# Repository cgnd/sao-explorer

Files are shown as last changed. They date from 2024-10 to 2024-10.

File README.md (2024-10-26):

---
typora-copy-images-to: ./images
---

# SAO Explorer v1

The SAO Explorer v1 is a [Simple Add-on](https://hackaday.io/project/175182-simple-add-ons-sao) (SAO) board that breaks out the 2x3 0.100" (2.54mm) SAO v2 header into a [mikroBUS](https://www.mikroe.com/mikrobus) socket and a couple SparkFun [Qwiic](https://www.sparkfun.com/qwiic) connectors. This makes it really easy to connect hundreds of different I2C breakout boards to a SAO host board—like a [Supercon badge](https://hackaday.com/2023/10/18/2023-hackaday-supercon-badge-welcome-to-the-vectorscope/)!—by quickly plugging in [MikroE Click](https://www.mikroe.com/click?interface*=i2c,i2c), [SparkFun Qwiic](https://www.sparkfun.com/categories/399), or [Adafruit STEMMA QT](https://www.adafruit.com/category/620) boards. No soldering required!

It also has a 2x5 0.050" (1.27mm) socket that allows a [Binho Nova](https://binho.io/products/usb-host-adaptor?variant=14141584343095) Multi-Protocol USB Host Adapter to be used as an I2C controller (instead of a badge). The [Binho Mission Control Software](https://support.binho.io/getting-started/binho-mission-control/download-and-installation) provides an easy-to-use GUI interface for quickly testing out new I2C devices without having to write a single line of code.

Entry for the [Supercon 8 - Add On Contest](https://hackaday.io/contest/197237-supercon-8-add-on-contest): https://hackaday.io/project/198465-sao-explorer

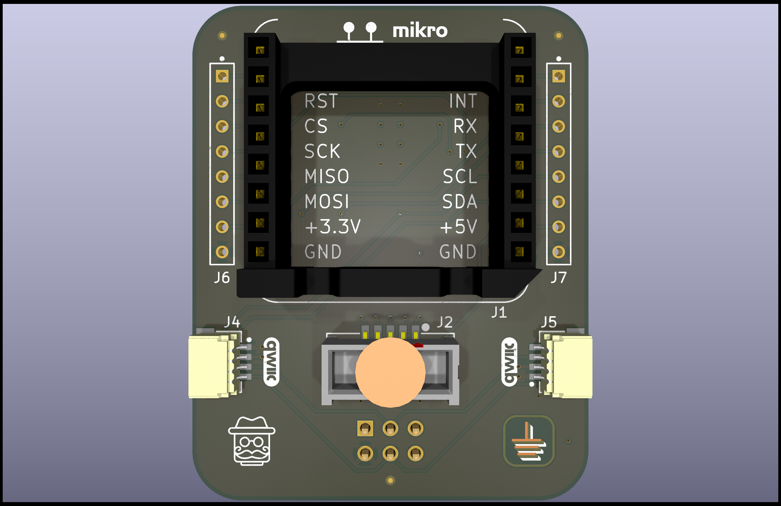
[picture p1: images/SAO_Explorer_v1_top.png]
SAO_Explorer_v1_top


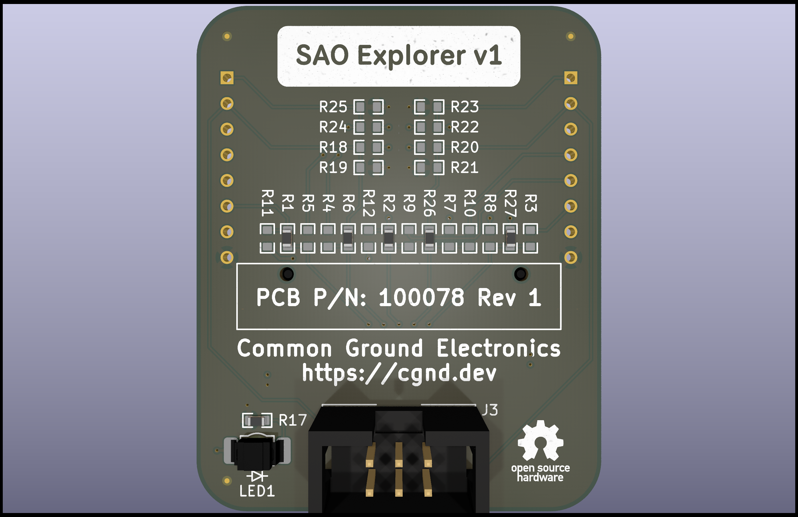
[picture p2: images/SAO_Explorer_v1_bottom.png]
SAO_Explorer_v1_bottom


## Pinout Decoder Ring

The I2C and GPIO1/2 pins on the SAO connector are directly connected to the I2C, INT, and RST pins on the mikroBUS socket.

By default, the Binho Nova is connected to the I2C, INT, RST, and PWM pins on the mikroBUS socket. However, by changing a couple jumper resistors on the back of the board, the Binho Nova can be connected to the UART or SPI pins on the mikroBUS socket instead.

| SAO Connector Pin | mikroBUS socket | Binho Nova Socket |
| --- | --- | --- |
| I2C SCL | I2C SCL | IO2/SCL/POCI/MISO *(populate R2, depopulate R9)* |
| I2C SDA | I2C SDA | IO0/SDA/CS0/INT0 *(populate R1, depopulate R5)* |
| GPIO1 | INT | IO1/DAC/CS1/INT1 *(populate R6, depopulate R4)* |
| GPIO2 | RST | IO3/RX/SCK *(populate R26, depopulate R7, R10)* |
| (not connected) | PWM | IO4/TX/PICO/MOSI *(populate R27, depopulate R3, R8)* |
| (not connected) | AN | IO1/DAC/CS1/INT1 *(populate R4, depopulate R6)* |
| (not connected) | UART TX | IO3/RX/SCK *(populate R7, depopulate R10, R26)* |
| (not connected) | UART RX | IO4/TX/PICO/MOSI *(populate R8, depopulate R3, R27)* |
| (not connected) | SPI SCK | IO3/RX/SCK *(populate R10, depopulate R7, R26)* |
| (not connected) | SPI POCI (MISO) | IO2/SCL/POCI/MISO *(populate R9, depopulate R2)* |
| (not connected) | SPI PICO (MOSI) | IO4/TX/PICO/MOSI *(populate R3, depopulate R8, R27)* |
| (not connected) | SPI CS | IO0/SDA/CS0/INT0 *(populate R5, depopulate R1)* |

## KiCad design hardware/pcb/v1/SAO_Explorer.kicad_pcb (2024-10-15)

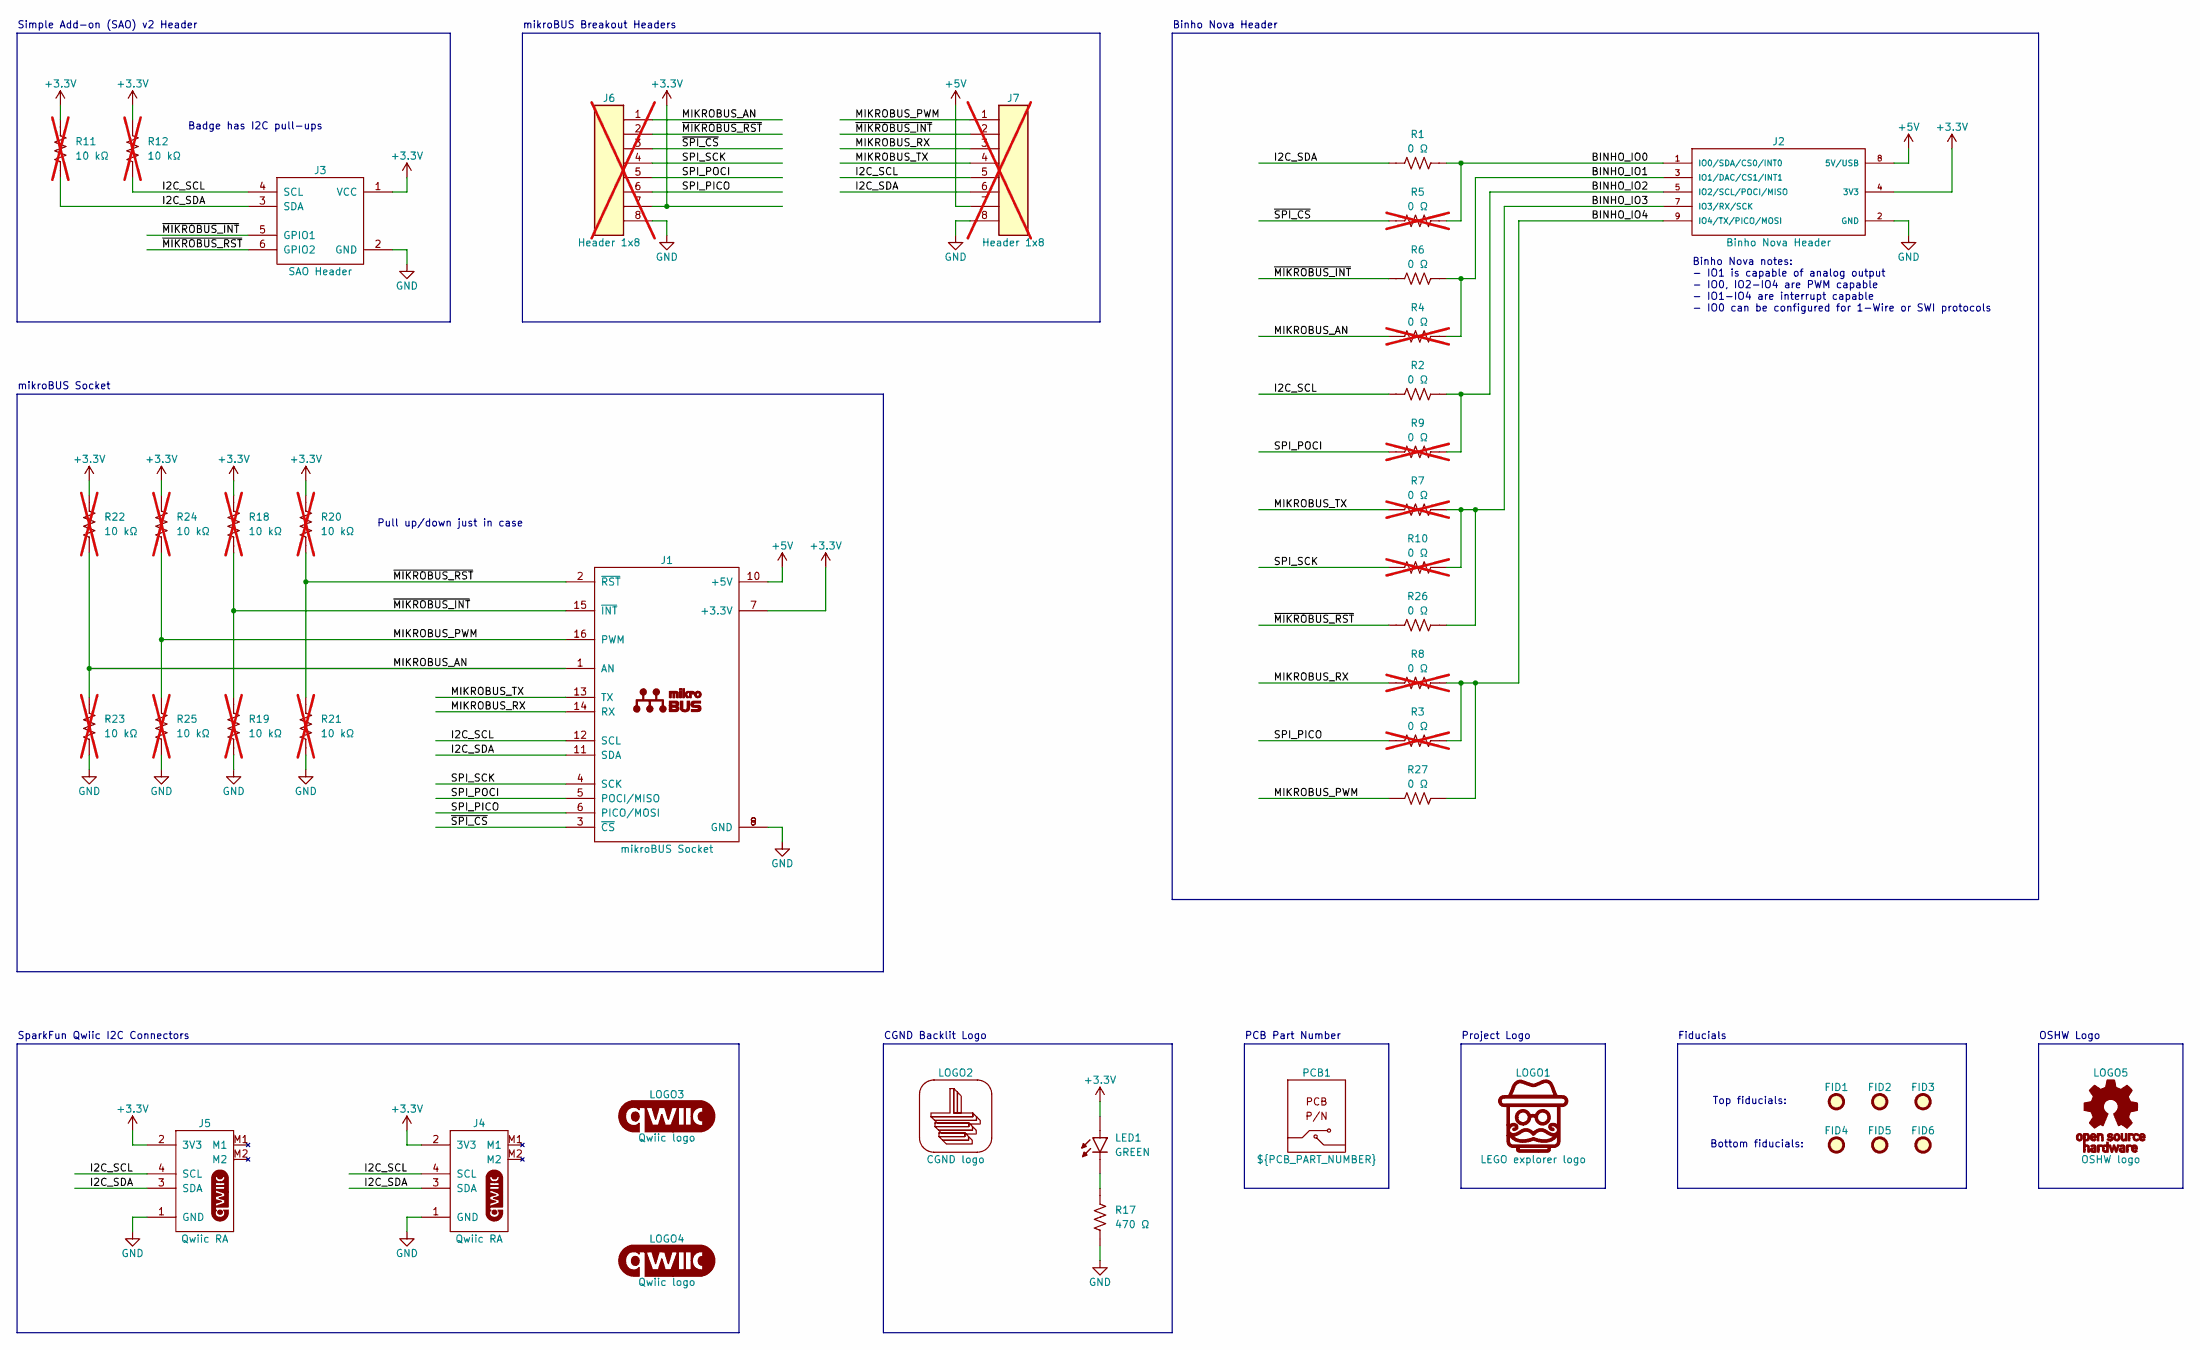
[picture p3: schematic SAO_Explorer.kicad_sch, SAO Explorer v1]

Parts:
FID1, FID2, FID3, FID4, FID5, FID6: Fiducial; FIDC50M100K100L
J1: mikroBUS Socket; MIKROE_MIKROE-4248; Manufacturer Part Number MIKROE-4248
J2: Binho Nova Header; SAMTEC_SHF-105-01-x-D-SM; Manufacturer Part Number SHF-105-01-L-D-SM-K-TR
J3: SAO Header; SHDRV6W64P254_3X2_1512X910H910_SAO_V2; Manufacturer Part Number SBH11-NBPC-D03-ST-BK
J4, J5: Qwiic RA; JST_SM04B-SRxS; Manufacturer Part Number SM04B-SRSS-TB(LF)(SN)
J6, J7: Header 1x8; HDRV8W67P254_8X1_2032X241H858; Manufacturer Part Number 68001-208HLF; not fitted
LED1: GREEN; SUNLED_XZVG45WT-9_CGND_LOGO; Manufacturer Part Number XZVG45WT-9
LOGO1: LEGO explorer logo; LOGO_LEGO_EXPLORER_OUTLINE_500X500_SILKSCREEN
LOGO2: CGND logo; LOGO_CGND_500X500_BACKLIT
LOGO3, LOGO4: Qwiic logo; LOGO_SPARKFUN_QWIIC_500X160_SILKSCREEN
LOGO5: OSHW logo; LOGO_OSHW_570X600_SILKSCREEN
PCB1: ${PCB_PART_NUMBER}; Manufacturer Part Number ${PCB_PART_NUMBER}
R1, R2, R6, R26, R27: 0 Ω; RESC160X80X55L25N; Manufacturer Part Number RC0603JR-070RL
R3, R4, R5, R7, R8, R9, R10: 0 Ω; RESC160X80X55L25N; Manufacturer Part Number RC0603JR-070RL; not fitted
R11, R12, R18, R19, R20, R21, R22, R23, R24, R25: 10 kΩ; RESC160X80X55L25N; Manufacturer Part Number RC0603JR-0710KL; not fitted
R17: 470 Ω; RESC160X80X55L25N; Manufacturer Part Number RC0603JR-07470RL

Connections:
+3.3V: J1.7 (+3.3V), J2.4 (3V3), J3.1 (VCC), J4.2 (3V3), J5.2 (3V3), J6.7, LED1.A (Anode), R11.2, R12.2, R18.2, R20.2, R22.2, R24.2
+5V: J1.10 (+5V), J2.8 (5V/USB), J7.7
/BINHO_IO0: J2.1 (IO0/SDA/CS0/INT0), R1.2, R5.2
/BINHO_IO1: J2.3 (IO1/DAC/CS1/INT1), R4.2, R6.2
/BINHO_IO2: J2.5 (IO2/SCL/POCI/MISO), R2.2, R9.2
/BINHO_IO3: J2.7 (IO3/RX/SCK), R7.2, R10.2, R26.2
/BINHO_IO4: J2.9 (IO4/TX/PICO/MOSI), R3.2, R8.2, R27.2
/I2C_SCL: J1.12 (SCL), J3.4 (SCL), J4.4 (SCL), J5.4 (SCL), J7.5, R2.1, R12.1
/I2C_SDA: J1.11 (SDA), J3.3 (SDA), J4.3 (SDA), J5.3 (SDA), J7.6, R1.1, R11.1
/MIKROBUS_AN: J1.1 (AN), J6.1, R4.1, R22.1, R23.2
/MIKROBUS_PWM: J1.16 (PWM), J7.1, R24.1, R25.2, R27.1
/MIKROBUS_RX: J1.14 (RX), J7.3, R8.1
/MIKROBUS_TX: J1.13 (TX), J7.4, R7.1
/SPI_PICO: J1.6 (PICO/MOSI), J6.6, R3.1
/SPI_POCI: J1.5 (POCI/MISO), J6.5, R9.1
/SPI_SCK: J1.4 (SCK), J6.4, R10.1
/~MIKROBUS_INT: J1.15 (~INT), J3.5 (GPIO1), J7.2, R6.1, R18.1, R19.2
/~MIKROBUS_RST: J1.2 (~RST), J3.6 (GPIO2), J6.2, R20.1, R21.2, R26.1
/~SPI_CS: J1.3 (~CS), J6.3, R5.1
GND: J1.8 (GND), J1.9 (GND), J2.2 (GND), J2.6 (GND), J2.10 (GND), J3.2 (GND), J4.1 (GND), J5.1 (GND), J6.8, J7.8, R17.1, R19.1, R21.1, R23.1, R25.1
unnamed: LED1.C (Cathode), R17.2

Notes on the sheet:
Simple Add-on (SAO) v2 Header
PCB Part Number
Bottom fiducials:
CGND Backlit Logo
Badge has I2C pull-ups
Project Logo
SparkFun Qwiic I2C Connectors
Binho Nova Header
Binho Nova notes: - IO1 is capable of analog output - IO0, IO2-IO4 are PWM capable - IO1-IO4 are interrupt capable - IO0 can be configured for 1-Wire or SWI protocols
Top fiducials:
Fiducials
mikroBUS Breakout Headers
mikroBUS Socket
OSHW Logo
Pull up/down just in case

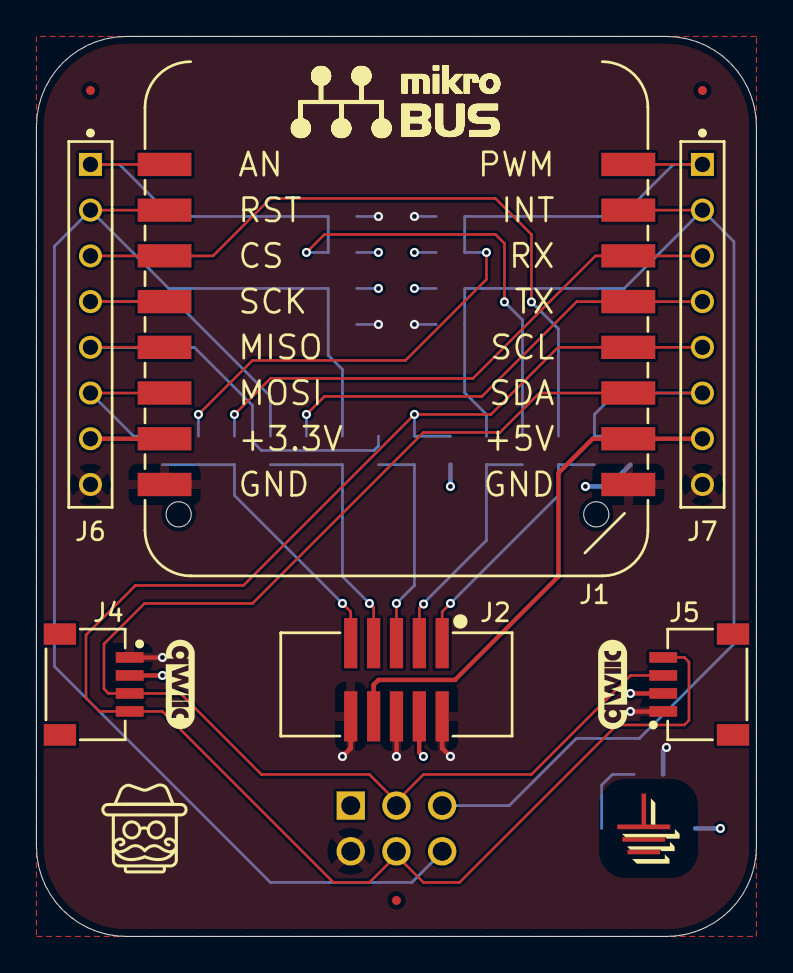
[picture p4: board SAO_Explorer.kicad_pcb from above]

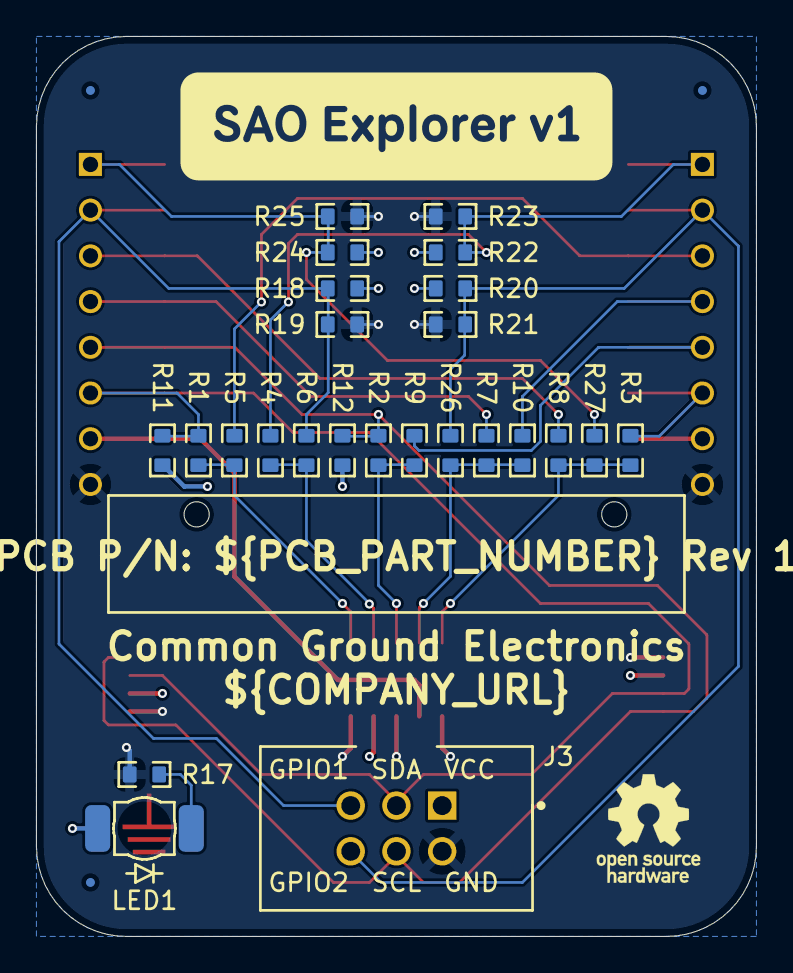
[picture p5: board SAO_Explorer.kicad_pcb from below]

Board: 4 copper layers, 40.0 x 50.0 mm, 42 parts (29 on the bottom side), 21 nets.

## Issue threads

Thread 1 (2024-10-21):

Support mikroBUS UART RX/TX from the SAO header

cdwilson, 2024-10-21:
The original [SAO v2 spec](https://docs.google.com/document/d/1EJqvkkLMAPsQ9VWF5A4elWoi0qMlKyr5Giw5rqRmtnM/edit?usp=sharing) has a "Serial/UART" section which allows using the GPIO1/GPIO2 pins on the SAO connector for UART.

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

Rev 1 does not have an option to connect the SAO GPIO1/2 pins to the UART pins on the mikroBUS connector. It would be nice if a future revision of the board had jumper options to allow these to be connected.

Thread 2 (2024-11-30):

Assembly guide

unwiredben, 2024-11-30:
Hi, Chris!  I was about to put this together finally, but I was looking for a guide to what resistors needed to be populated for the default case.  Can you put up a PDF of the schematic or a board population guide?

Thanks!

cdwilson, 2024-12-03:
Hey Ben, sorry for the delayed response on this!

I need to update the README, but in the mean time (in case you haven't already figured it out), the SAO Explorer board is designed to be connected to a SAO host port on a badge without having to solder _any_ of the surface mount resistors.

However, the main caveat is that only the +3.3V, I2C pins, and the GPIO1/2 from the SAO host are connected to the mikroBUS socket (SPI/UART/+5V/etc on the Click board is not connected). This limits the usage of the SAO Explorer to mikroBUS Click boards that only require I2C and a GPIO or two.

The reason why I included the surface mount resistor footprints is that the SAO Explorer board _**also**_ allows a [Binho Nova](https://binho.io/products/usb-host-adaptor?variant=14141584343095) Multi-Protocol USB Host Adapter to be used as an I2C controller instead of a badge (do NOT connect both at the same time). The Binho Nova can be connected to the SPI/UART/etc on the Click board as long as the jumper resistors are connected correctly (note that not all functionality can be enabled simultaneously). If you don’t have a Binho Nova, you can ignore the J2 connector and leave all of the surface mount resistors on the board DNP.

This table in the README details the pinout between the “SAO Connector Pin” <—> “mikroBUS Socket Pin" (and also includes details on the resistor stuffing options for the Binho Nova connector): https://github.com/cgnd/sao-explorer?tab=readme-ov-file#pinout-decoder-ring

You can find a PDF of the schematic in the release zip file on the releases page: https://github.com/cgnd/sao-explorer/releases/tag/100078%2FRev1

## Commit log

2024-10-15 Add 100078 Rev 1 schematic and layout
    [SAO_Explorer.kicad_pcb, SAO_Explorer.kicad_sch]
2024-10-15 Fix schematic net label formatting
    [SAO_Explorer.kicad_sch]
2024-10-15 Update schematic export settings

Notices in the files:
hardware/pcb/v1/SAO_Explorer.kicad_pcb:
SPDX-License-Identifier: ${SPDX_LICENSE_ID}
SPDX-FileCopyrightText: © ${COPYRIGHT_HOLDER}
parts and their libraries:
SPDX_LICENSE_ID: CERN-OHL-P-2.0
